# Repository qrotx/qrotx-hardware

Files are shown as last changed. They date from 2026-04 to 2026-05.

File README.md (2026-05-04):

# qrotx Singleband Transmitter Hardware

This is work in progress, it has not yet been tested. Description and calculations will be added later.

## Cloning

This repository uses a git submodule for the KiCad symbol and footprint libraries. Clone with:

```bash
git clone --recurse-submodules git@github.com:qrotx/qrotx-singleband-hw.git
```

If you already cloned without `--recurse-submodules`, initialize the submodule with:

```bash
git submodule update --init
```

## Assembly

### NUCLEO-G474RE Board Modifications

The NUCLEO-G474RE board requires the following modifications before mounting on the PCB.
Reference: [UM2505 STM32G4 Nucleo-64 boards (MB1367) user manual](https://www.st.com/resource/en/user_manual/um2505-stm32g4-nucleo64-boards-mb1367-stmicroelectronics.pdf)

#### Power Supply (JP5)

Change jumper JP5 from the default **5V_STLK** position to the **E5V** position. This powers the
Nucleo board from the E5V pin supplied by the PCB instead of from USB.

#### HSE Clock — Oscillator from External PF0 (Section 7.5.1)

Modify the following solder bridges to configure the HSE clock input for an external
oscillator on PF0:

| Solder Bridge | Default | Required |
|---|---|---|
| SB24 | OFF | OFF |
| SB25 | ON | OFF |
| SB26 | ON | OFF |
| SB27 | OFF | OFF |
| SB28 | OFF | ON |

## License
These hardware designs are made available under the CERN Open Hardware Licence Version 2 - Strongly Reciprocal.
See [LICENSE](LICENSE) for the full text.

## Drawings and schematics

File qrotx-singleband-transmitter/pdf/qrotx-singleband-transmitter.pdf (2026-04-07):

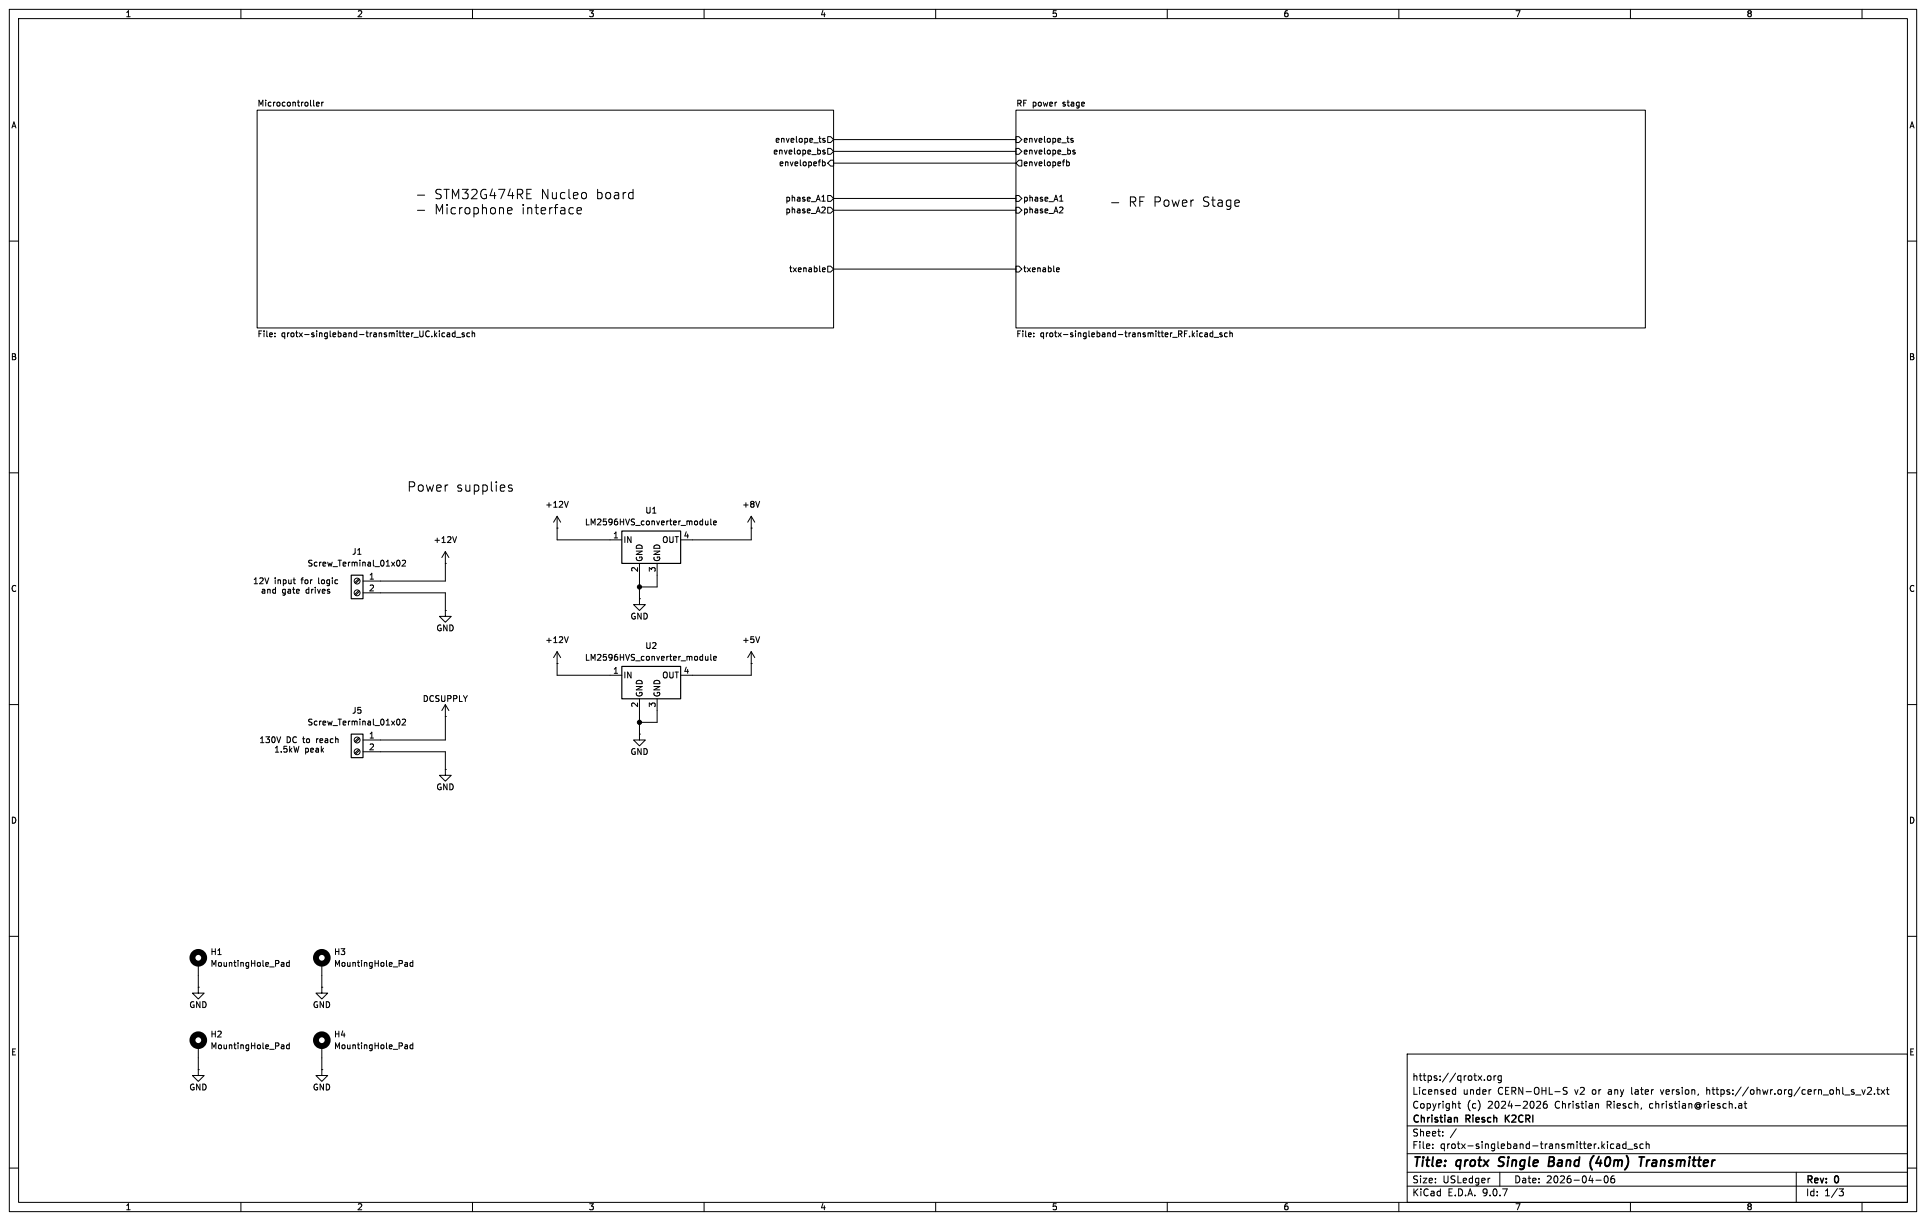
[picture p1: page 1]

txenable Microcontroller File: qrotx-singleband-transmitter_UC.kicad_sch

envelope_bs RF power stage File: qrotx-singleband-transmitter_RF.kicad_sch

12V input for logic and gate drives

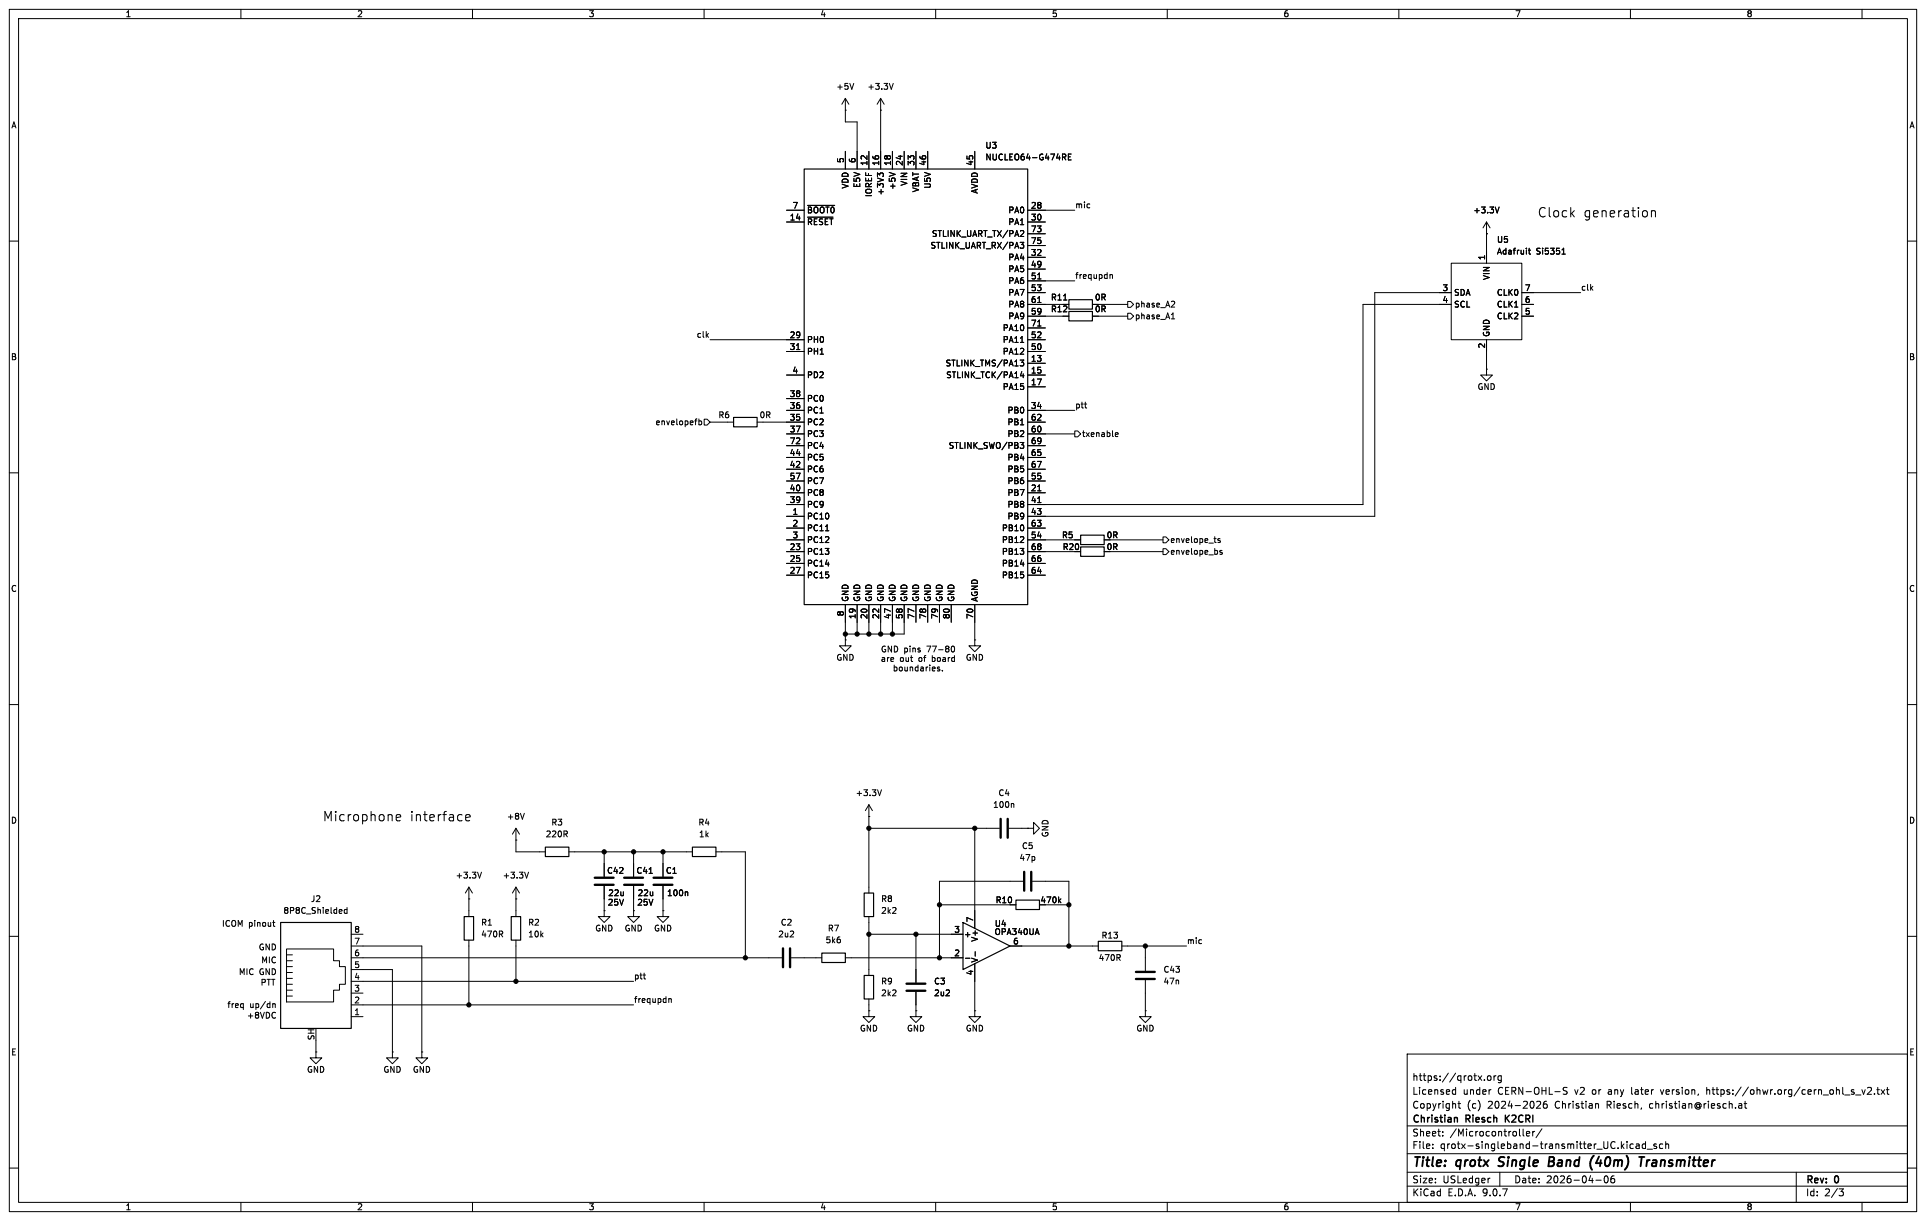
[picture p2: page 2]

6 GND 19 IOREF 12 GND 20 +3V3 16 GND 22 +5V 18 GND 47 VIN 24 GND 58 VBAT 33 GND 77 U5V 46 GND 78 GND 79 GND 80 AVDD 45 AGND 70 PA0 28 PA1 30 STLINK_UART_TX/PA2 73 STLINK_UART_RX/PA3 75 PA4 32 PA5 49 PA6 51 PA7 53 PA8 61 PA9 59 PA10 71 PA11 52 PA12 50 STLINK_TMS/PA13 13 STLINK_TCK/PA14 15 PA15 17 PB0 34 PB1 62 PB2 60 STLINK_SWO/PB3 69 PB4 65 PB5 67 PB6 55 PB7 21 PB8 41 PB9 43 PB10 63 PB12 54 PB13 68 PB14 66 PB15 64

6 GND 19 IOREF 12 GND 20 +3V3 16 GND 22 +5V 18 GND 47 VIN 24 GND 58 VBAT 33 GND 77 U5V 46 GND 78 GND 79 GND 80 AVDD 45 AGND 70 PA0 28 PA1 30 STLINK_UART_TX/PA2 73 STLINK_UART_RX/PA3 75 PA4 32 PA5 49 PA6 51 PA7 53 PA8 61 PA9 59 PA10 71 PA11 52 PA12 50 STLINK_TMS/PA13 13 STLINK_TCK/PA14 15 PA15 17 PB0 34 PB1 62 PB2 60 STLINK_SWO/PB3 69 PB4 65 PB5 67 PB6 55 PB7 21 PB8 41 PB9 43 PB10 63 PB12 54 PB13 68 PB14 66 PB15 64 R11 0R

are out of board

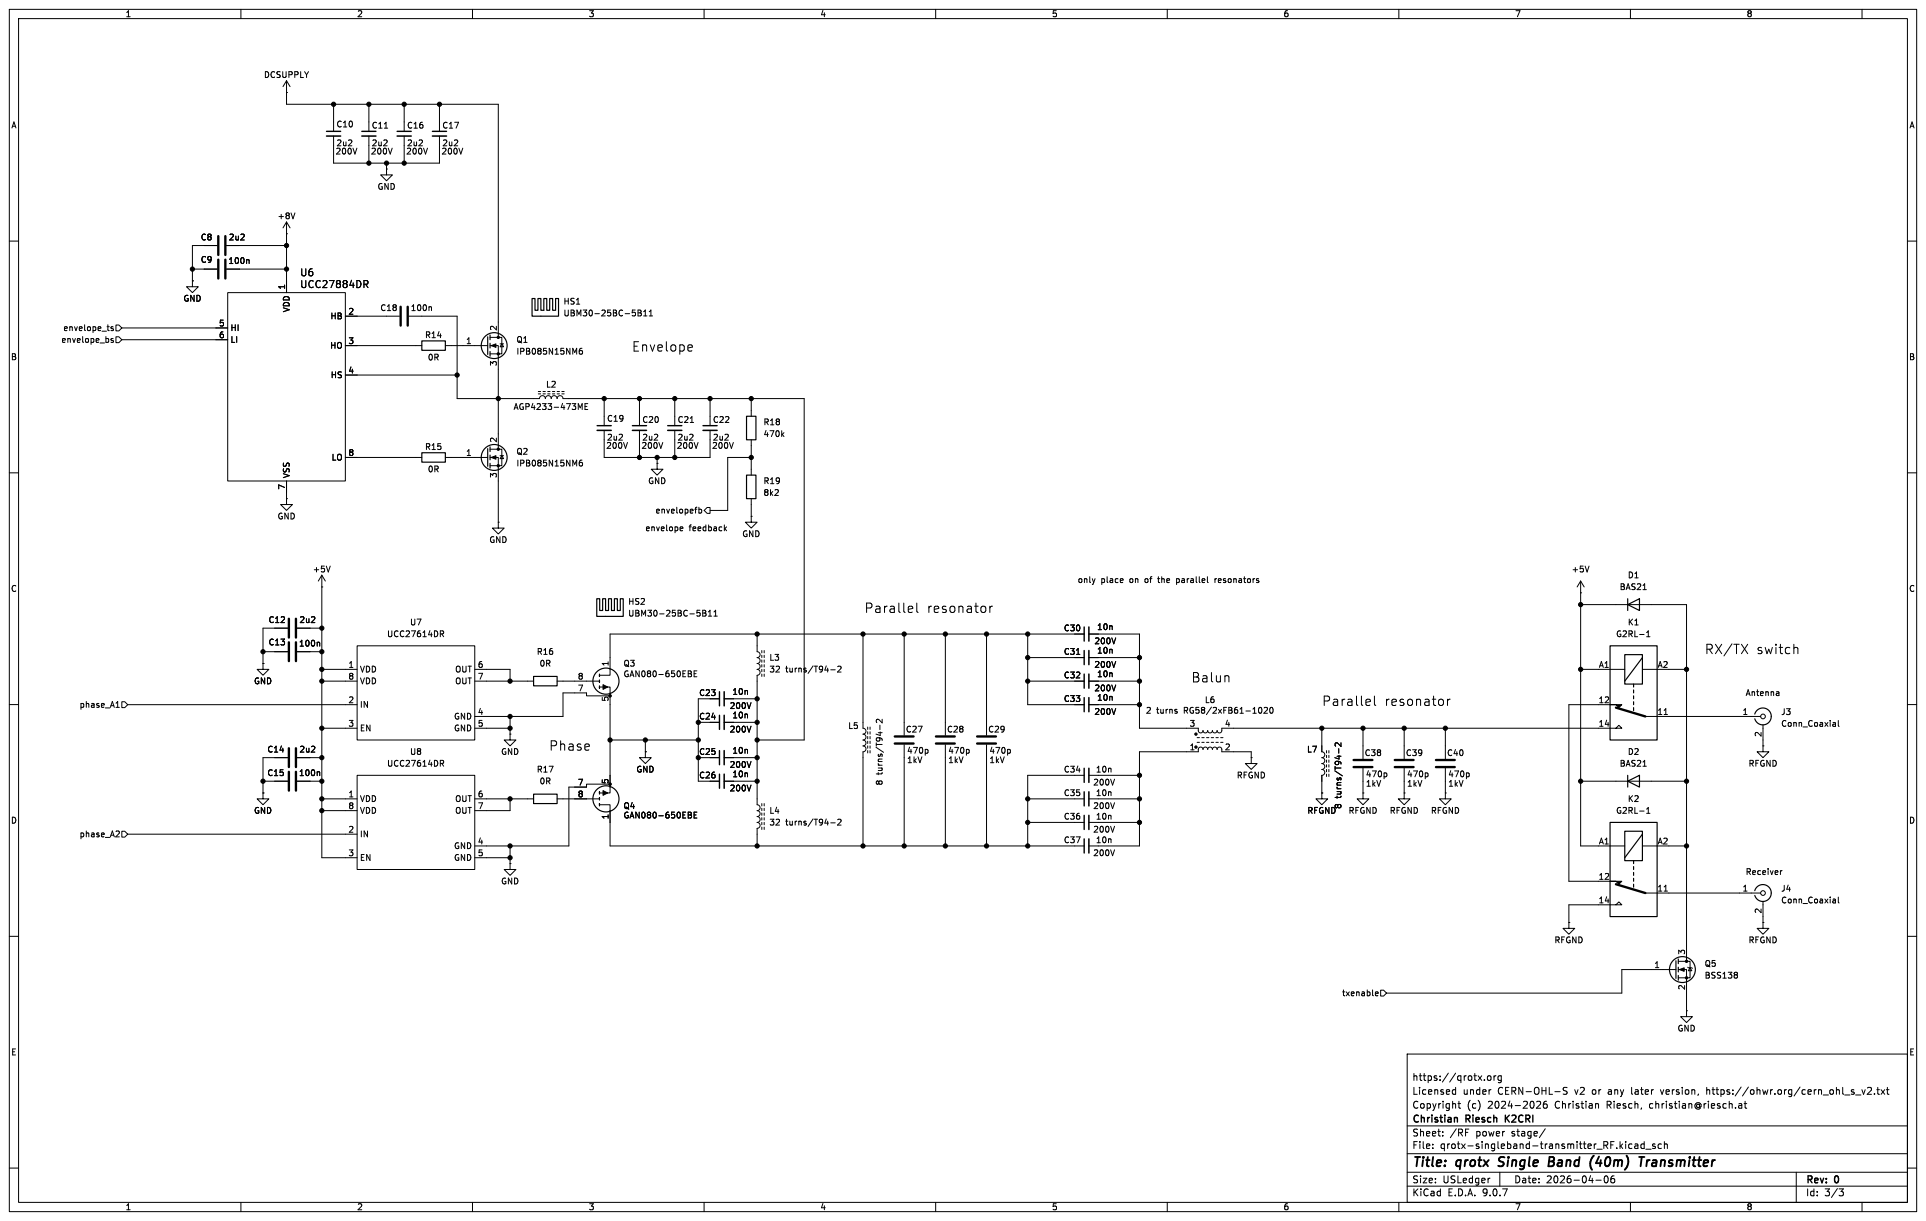
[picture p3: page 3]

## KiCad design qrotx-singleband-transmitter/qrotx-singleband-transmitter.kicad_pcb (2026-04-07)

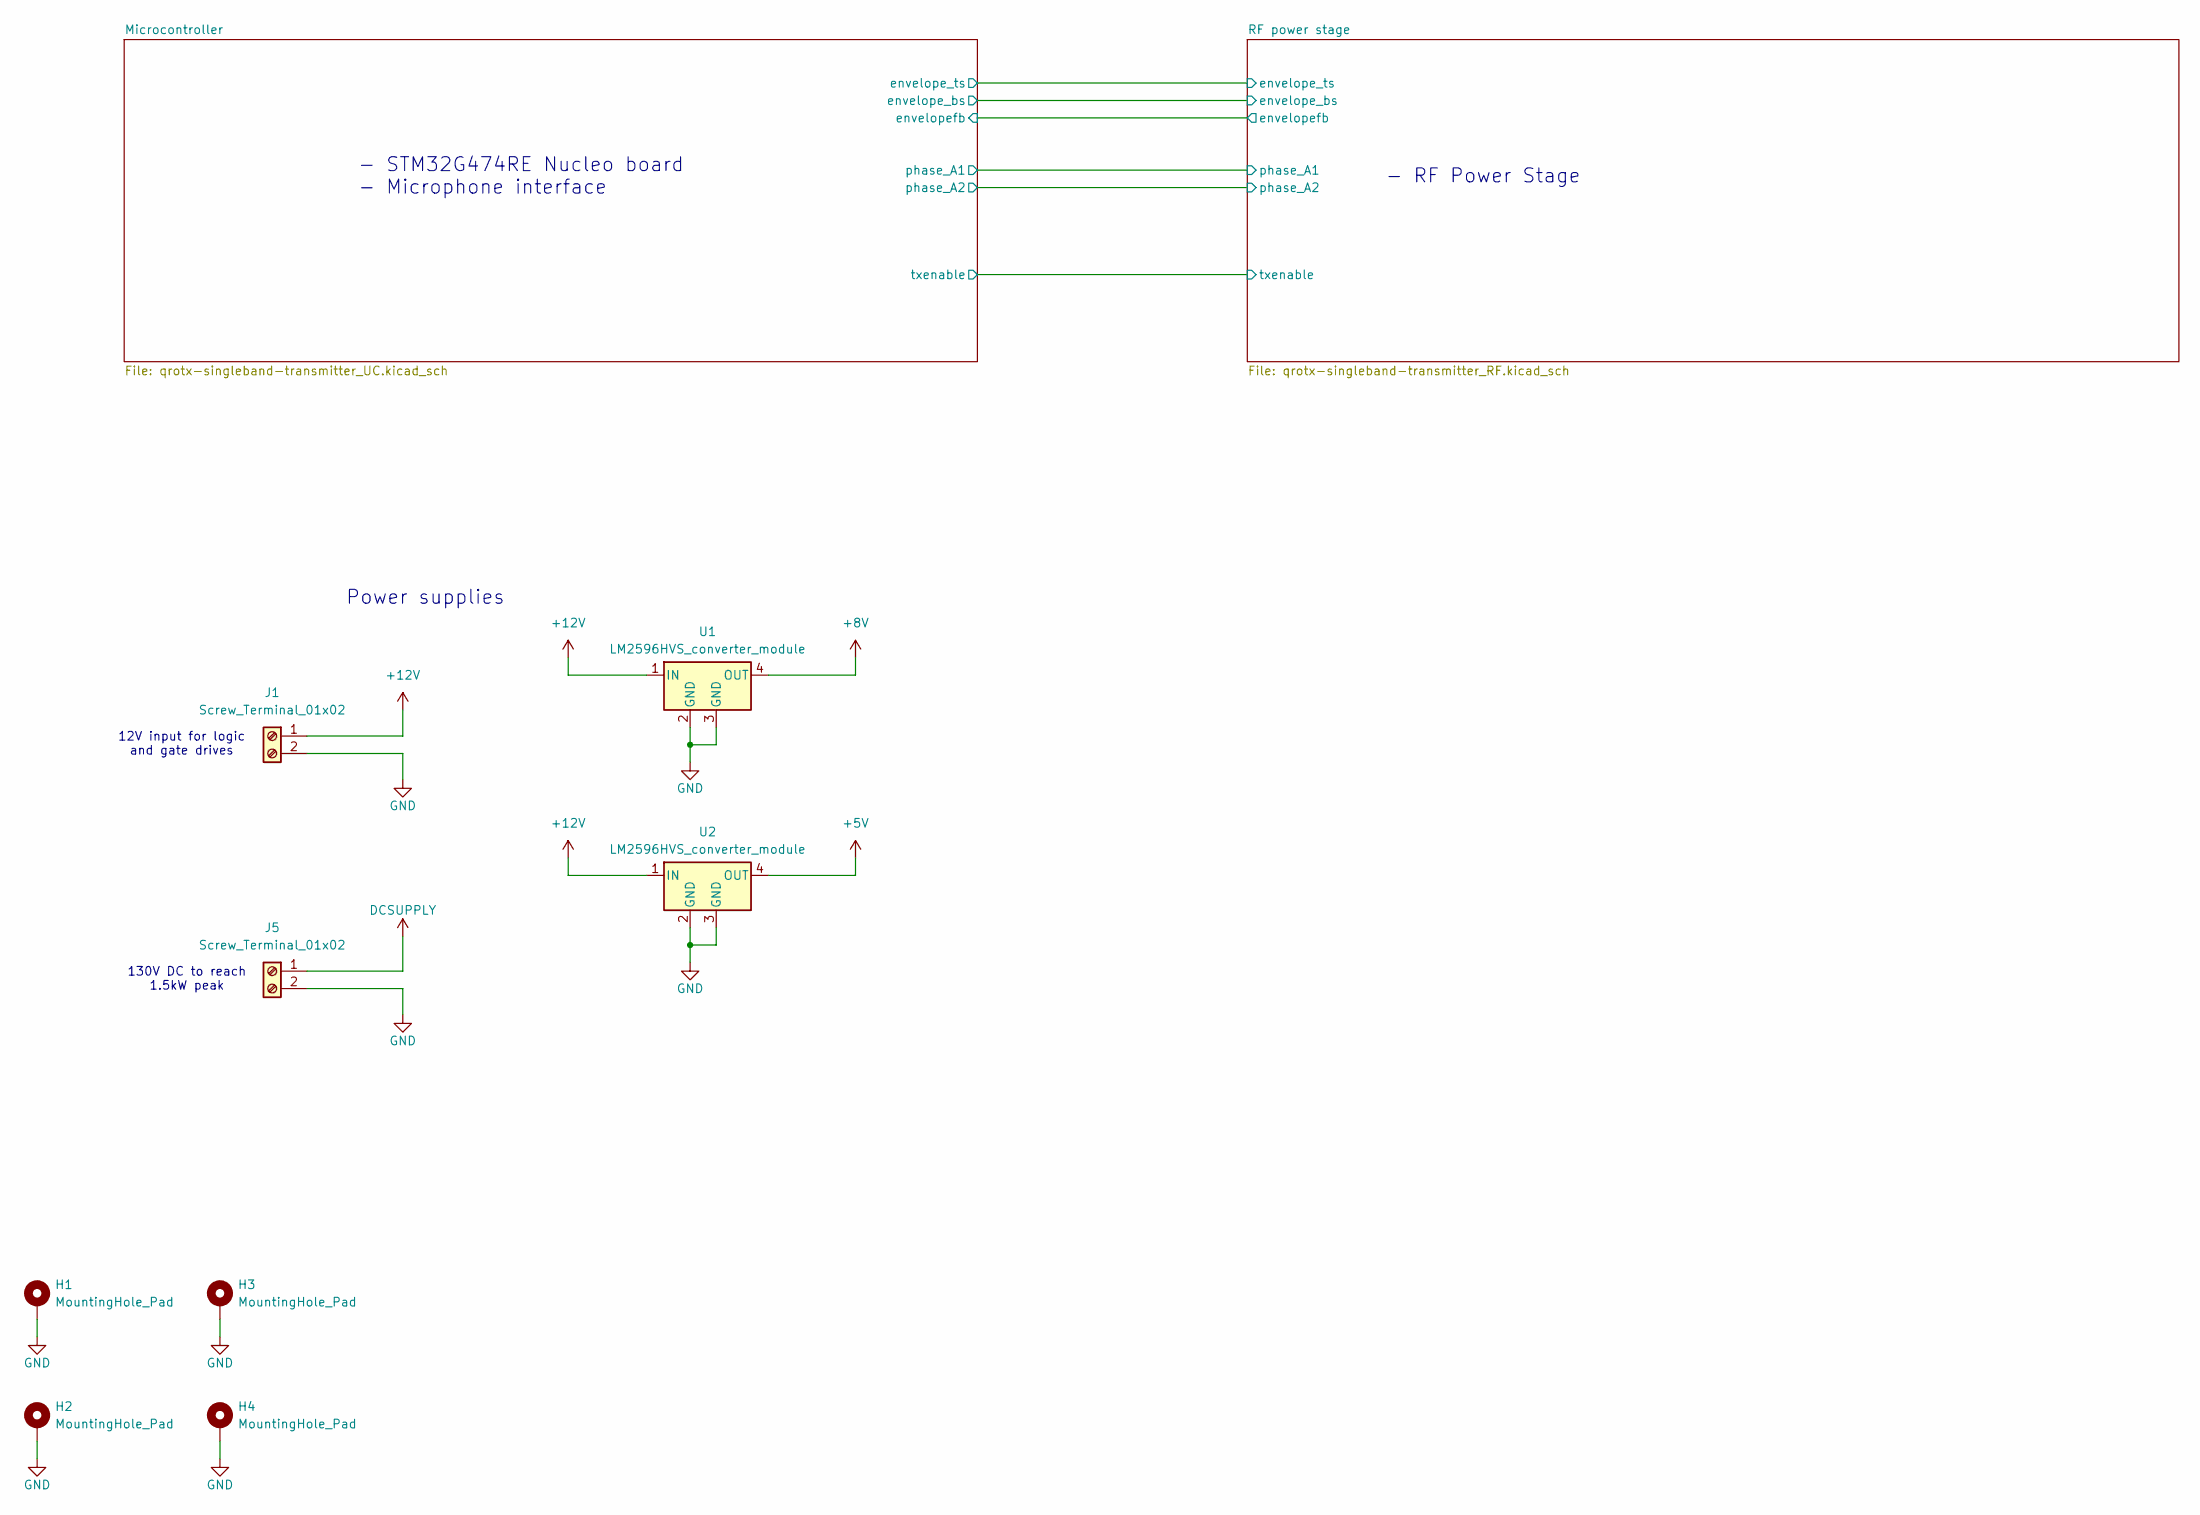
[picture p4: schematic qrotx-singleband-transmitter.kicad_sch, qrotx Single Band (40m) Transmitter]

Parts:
H1, H2, H3, H4: MountingHole_Pad; MountingHole_3.2mm_M3_Pad
J1, J5: Screw_Terminal_01x02; PhoenixContact_GMSTBV_2,5_2-GF-7,62_1x02_P7.62mm_Vertical_T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
U1, U2: LM2596HVS_converter_module; LM2596HVS module

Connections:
+5V: U2.4 (OUT); also elsewhere on the board
+8V: U1.4 (OUT); also elsewhere on the board
+12V: J1.1, U1.1 (IN), U2.1 (IN)
DCSUPPLY: J5.1; also elsewhere on the board
GND: H1.1, H2.1, H3.1, H4.1, J1.2, J5.2, U1.2 (GND), U1.3 (GND), U2.2 (GND), U2.3 (GND); also elsewhere on the board

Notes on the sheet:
Power supplies
130V DC to reach 1.5kW peak
- STM32G474RE Nucleo board - Microphone interface
12V input for logic and gate drives
- RF Power Stage

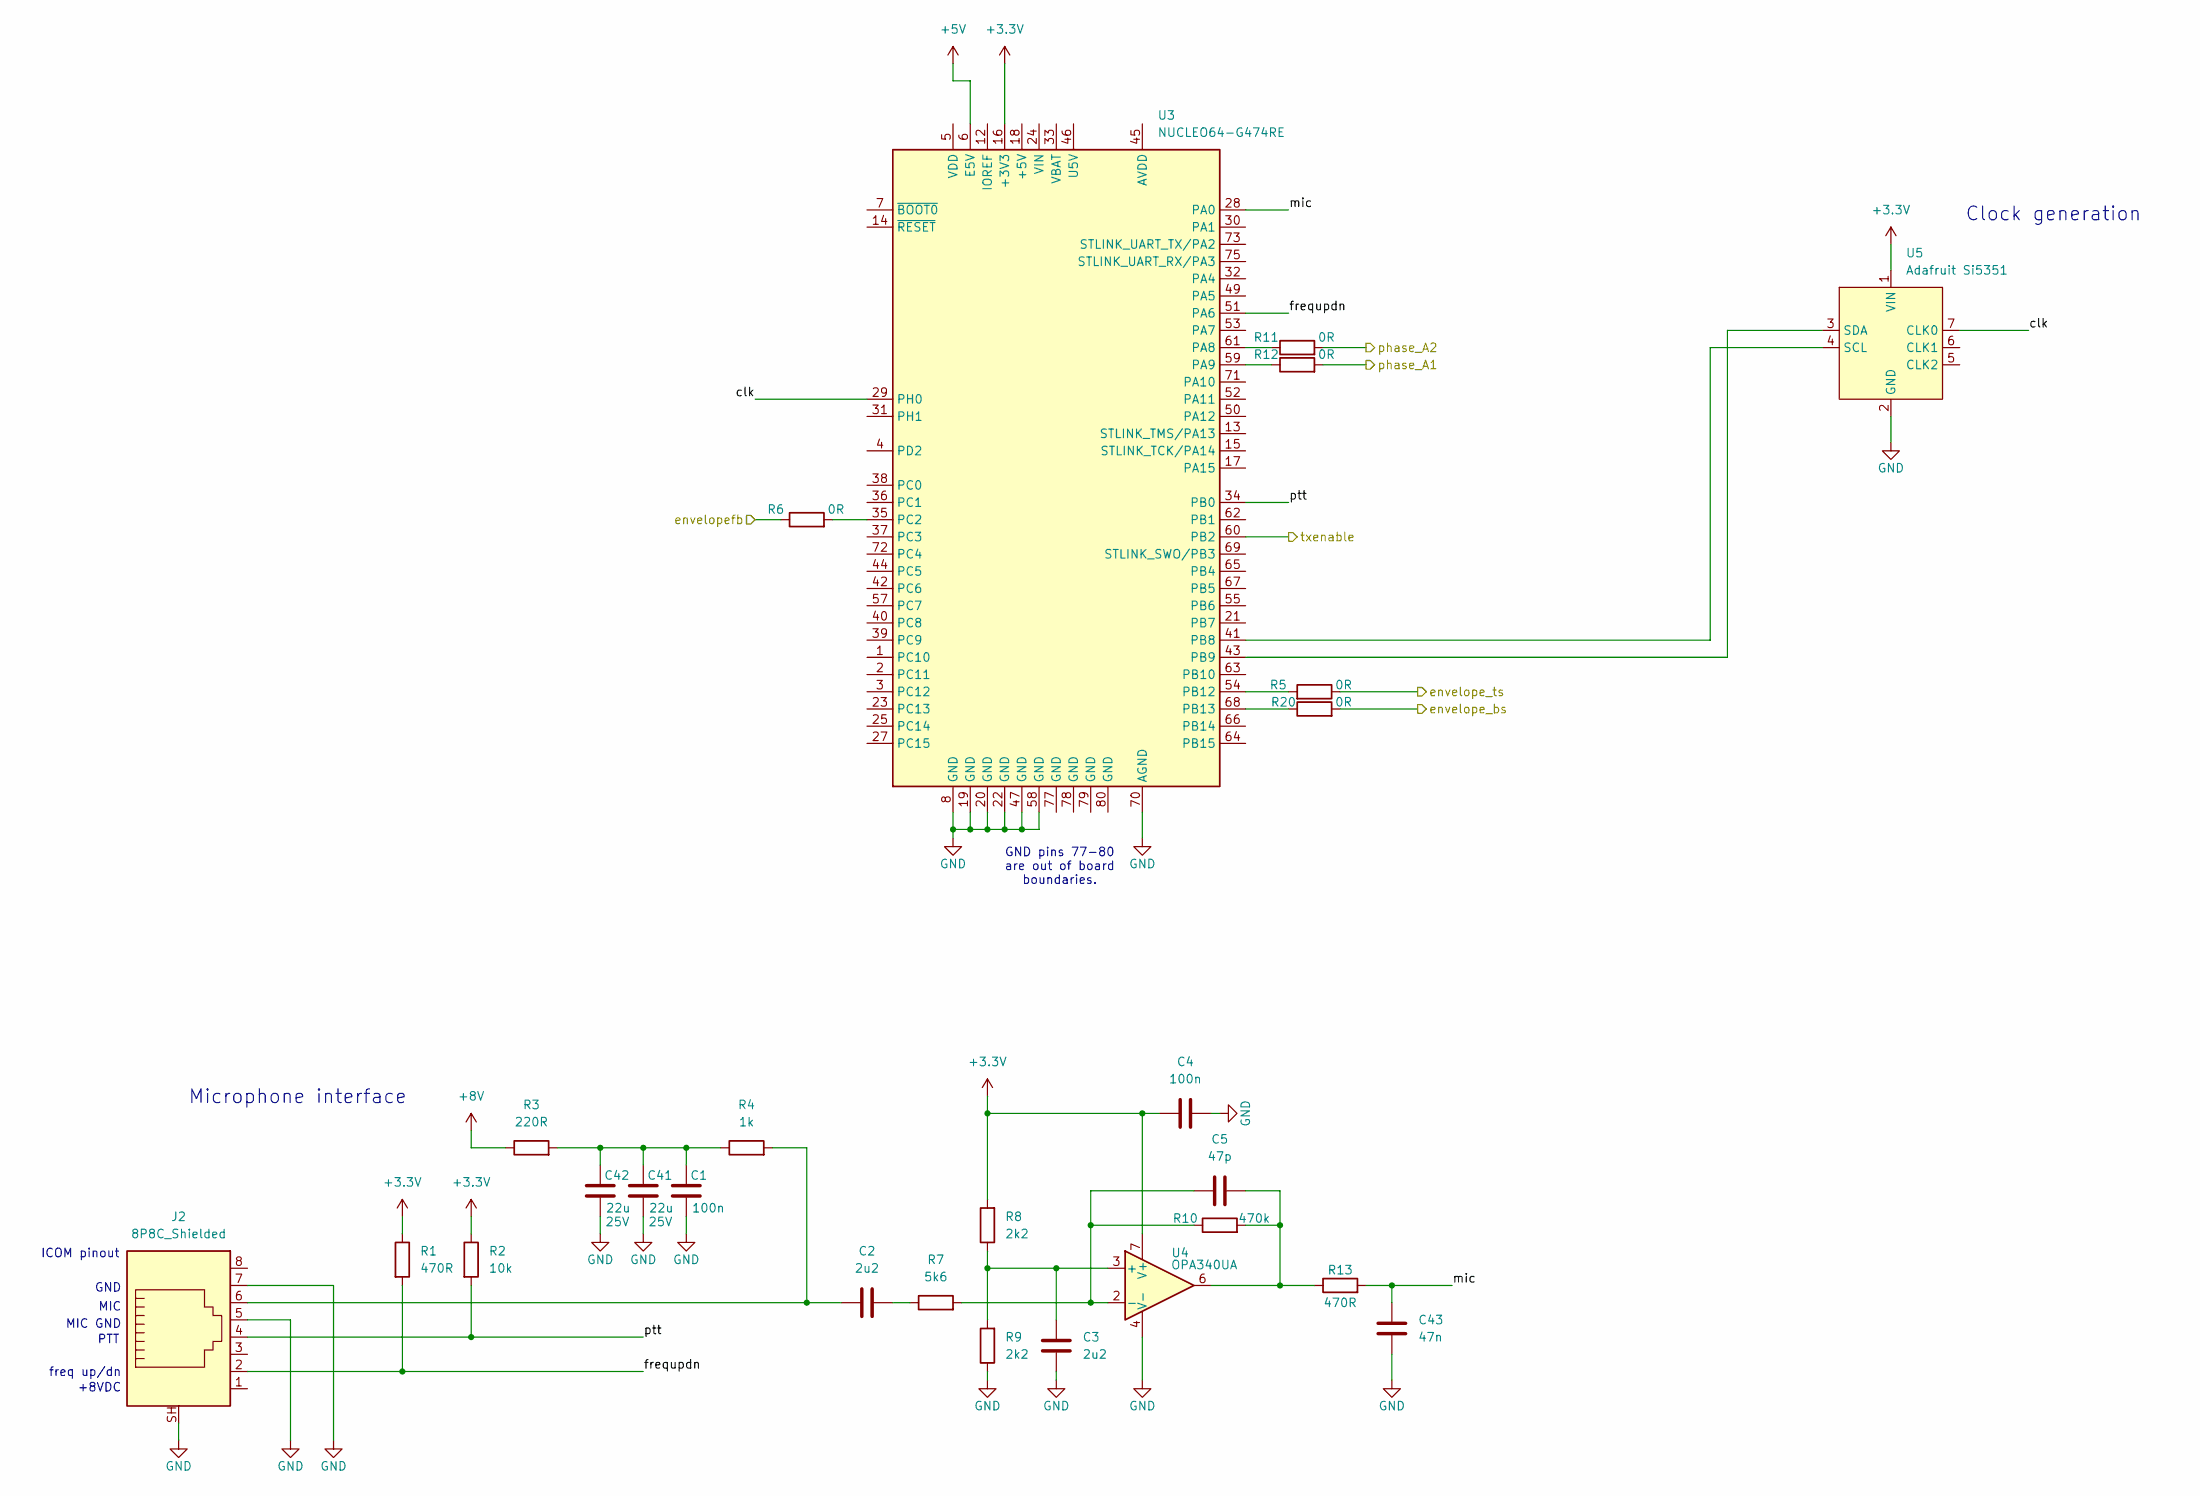
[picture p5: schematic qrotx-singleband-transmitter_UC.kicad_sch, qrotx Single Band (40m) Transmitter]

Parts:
C1, C4: 100n; C_0603_1608Metric
C2, C3: 2u2; C_0603_1608Metric
C5: 47p; C_0603_1608Metric
C41, C42: 22u; C_1210_3225Metric; Voltage 25V
C43: 47n; C_0603_1608Metric
J2: 8P8C_Shielded; RJ45_Amphenol_RJHSE5380
R1, R13: 470R; R_0603_1608Metric
R2: 10k; R_0603_1608Metric
R3: 220R; R_0603_1608Metric
R4: 1k; R_0603_1608Metric
R5, R6, R11, R12, R20: 0R; R_0603_1608Metric
R7: 5k6; R_0603_1608Metric
R8, R9: 2k2; R_0603_1608Metric
R10: 470k; R_0603_1608Metric
U3: NUCLEO64-G474RE; ST_Morpho_Connector_64_STLink
U4: OPA340UA; SOIC-8_3.9x4.9mm_P1.27mm
U5: Adafruit Si5351; Adafruit_Si5351

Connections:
+3.3V: C4.1, R1.1, R2.1, R8.2, U3.16 (+3V3), U4.7 (V+), U5.1 (VIN)
+5V: U3.6 (E5V); also elsewhere on the board
+8V: R3.1; also elsewhere on the board
/Microcontroller/clk: U3.29 (PH0), U5.7 (CLK0)
/Microcontroller/envelope_bs: R20.2; also elsewhere on the board
/Microcontroller/envelope_ts: R5.1; also elsewhere on the board
/Microcontroller/envelopefb: R6.1; also elsewhere on the board
/Microcontroller/frequpdn: J2.2, R1.2, U3.51 (PA6)
/Microcontroller/mic: C43.1, R13.2, U3.28 (PA0)
/Microcontroller/phase_A1: R12.2; also elsewhere on the board
/Microcontroller/phase_A2: R11.2; also elsewhere on the board
/Microcontroller/ptt: J2.4, R2.2, U3.34 (PB0)
/Microcontroller/txenable: U3.60 (PB2); also elsewhere on the board
GND: C1.2, C3.2, C4.2, C41.2, C42.2, C43.2, J2.5, J2.7, J2.SH, R9.1, U3.8 (GND), U3.19 (GND), U3.20 (GND), U3.22 (GND), U3.47 (GND), U3.58 (GND), U3.70 (AGND), U4.4 (V-), U5.2 (GND); also elsewhere on the board
unnamed: C1.1, C41.1, C42.1, R3.2, R4.1
unnamed: C2.1, J2.6, R4.2
unnamed: C2.2, R7.1
unnamed: C5.2, R10.2, R13.1, U4.6
unnamed: R11.1, U3.61 (PA8)
unnamed: R12.1, U3.59 (PA9)
unnamed: U3.41 (PB8), U5.4 (SCL)
unnamed: U3.43 (PB9), U5.3 (SDA)
unnamed: R5.2, U3.54 (PB12)
unnamed: R20.1, U3.68 (PB13)
unnamed: R6.2, U3.35 (PC2)
unnamed: C3.1, R8.1, R9.2, U4.3 (+)
unnamed: C5.1, R7.2, R10.1, U4.2 (-)

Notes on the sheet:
freq up/dn
ICOM pinout
GND
MIC
Clock generation
GND pins 77-80 are out of board boundaries.
+8VDC
PTT
Microphone interface
MIC GND

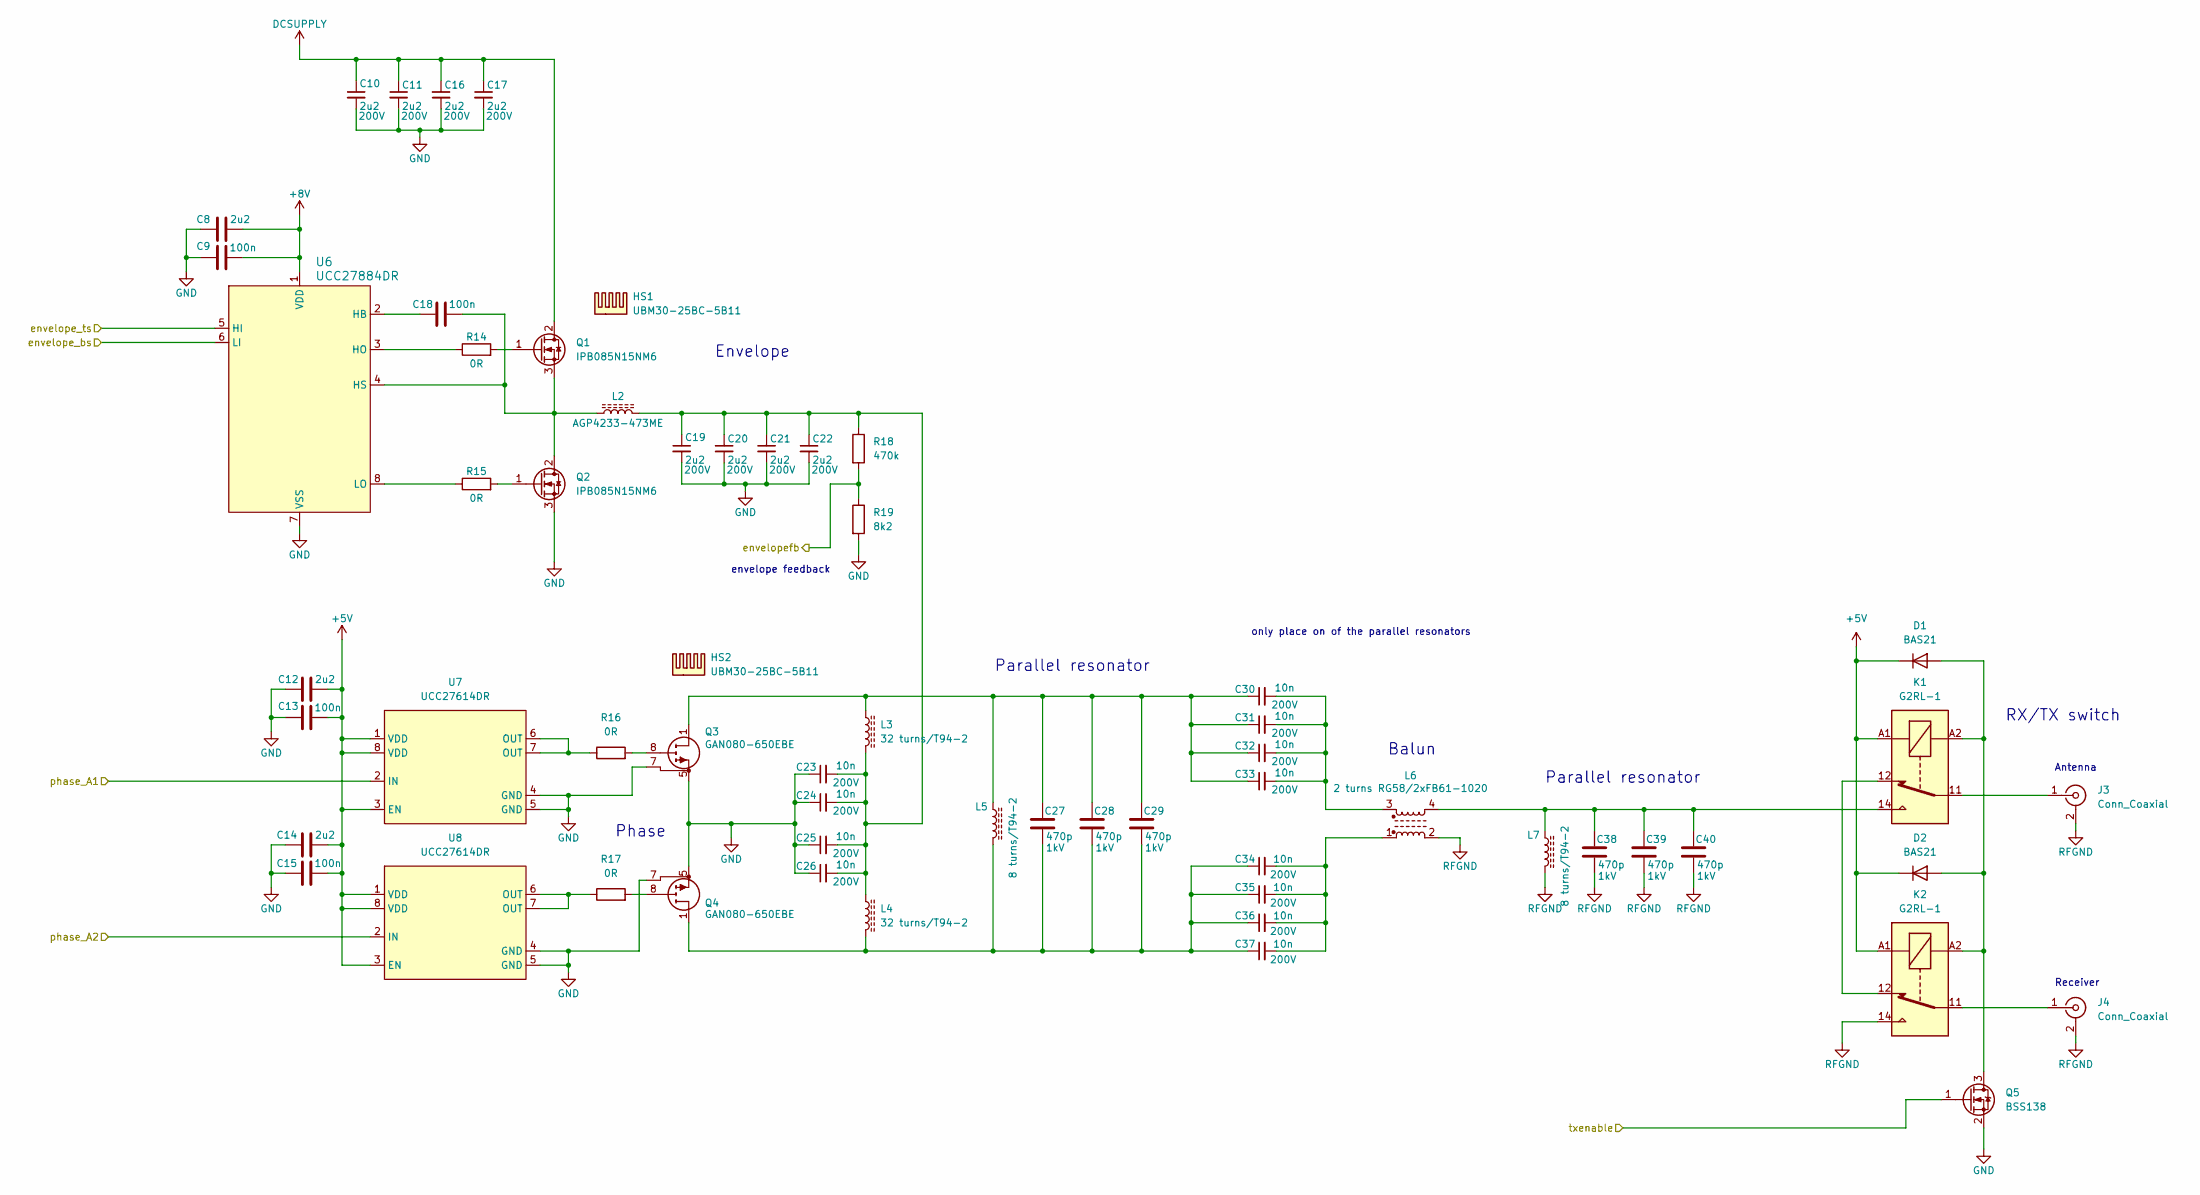
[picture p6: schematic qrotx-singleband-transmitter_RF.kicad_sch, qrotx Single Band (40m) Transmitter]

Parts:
C8, C12, C14: 2u2; C_0603_1608Metric
C9, C13, C15, C18: 100n; C_0603_1608Metric
C10, C11, C16, C17, C19, C20, C21, C22: 2u2; C_2220_5750Metric; Voltage 200V
C23, C24, C25, C26, C30, C31, C32, C33, C34, C35, C36, C37: 10n; C_1206_3216Metric; Voltage 200V
C27, C28, C29, C38, C39, C40: 470p; C_1206_3216Metric; Voltage 1kV
D1, D2: BAS21; SOT-23
HS1, HS2: UBM30-25BC-5B11; Heatsink_Alpha_UBM30-xxBP
J3: Conn_Coaxial; RF_output_pins
J4: Conn_Coaxial; SMA_Amphenol_901-144_Vertical
K1, K2: G2RL-1; Relay_SPDT_Omron_G2RL-1
L2: AGP4233-473ME; AGP4233-682-154
L3, L4: 32 turns/T94-2; t94-2_inductor_narrow
L5, L7: 8 turns/T94-2; t94-2_inductor
L6: 2 turns RG58/2xFB61-1020; tline_balun_pads
Q1, Q2: IPB085N15NM6; TO-263-2_ThermalVias
Q3, Q4: GAN080-650EBE; DFN8080-8_ThermalVias
Q5: BSS138; SOT-23
R14, R15, R16, R17: 0R; R_0603_1608Metric
R18: 470k; R_0603_1608Metric
R19: 8k2; R_0603_1608Metric
U6: UCC27884DR; SOIC-8_3.9x4.9mm_P1.27mm
U7, U8: UCC27614DR; SOIC-8_3.9x4.9mm_P1.27mm

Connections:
+5V: C12.2, C13.2, C14.2, C15.2, D1.3 (K), D2.3 (K), K1.A1, K2.A1, U7.1 (VDD), U7.3 (EN), U7.8 (VDD), U8.1 (VDD), U8.3 (EN), U8.8 (VDD); also elsewhere on the board
+8V: C8.2, C9.2, U6.1 (VDD); also elsewhere on the board
/Microcontroller/envelope_bs: U6.6 (LI); also elsewhere on the board
/Microcontroller/envelope_ts: U6.5 (HI); also elsewhere on the board
/Microcontroller/envelopefb: R18.2, R19.1; also elsewhere on the board
/Microcontroller/phase_A1: U7.2 (IN); also elsewhere on the board
/Microcontroller/phase_A2: U8.2 (IN); also elsewhere on the board
/Microcontroller/txenable: Q5.1 (G); also elsewhere on the board
DCSUPPLY: C10.1, C11.1, C16.1, C17.1, Q1.2 (D); also elsewhere on the board
GND: C8.1, C9.1, C10.2, C11.2, C12.1, C13.1, C14.1, C15.1, C16.2, C17.2, C19.2, C20.2, C21.2, C22.2, C23.1, C24.1, C25.1, C26.1, Q2.3 (S), Q3.5 (S), Q3.6 (S), Q3.7 (SS), Q3.9 (S), Q4.5 (S), Q4.6 (S), Q4.7 (SS), Q4.9 (S), Q5.2 (S), R19.2, U6.7 (VSS), U7.4 (GND), U7.5 (GND), U8.4 (GND), U8.5 (GND); also elsewhere on the board
unnamed: C19.1, C20.1, C21.1, C22.1, C23.2, C24.2, C25.2, C26.2, L2.2, L3.2, L4.1, R18.1
unnamed: C27.1, C28.1, C29.1, C30.1, C31.1, C32.1, C33.1, L3.1, L5.1, Q3.1 (D), Q3.2 (D), Q3.3 (D), Q3.4 (D)
unnamed: C27.2, C28.2, C29.2, C34.1, C35.1, C36.1, C37.1, L4.2, L5.2, Q4.1 (D), Q4.2 (D), Q4.3 (D), Q4.4 (D)
unnamed: C30.2, C31.2, C32.2, C33.2, L6.3
unnamed: C34.2, C35.2, C36.2, C37.2, L6.1
unnamed: C38.1, C39.1, C40.1, K1.14, L6.4, L7.1
unnamed: D1.1 (A), D2.1 (A), K1.A2, K2.A2, Q5.3 (D)
unnamed: J3.1 (In), K1.11
unnamed: J4.1 (In), K2.11
unnamed: K1.12, K2.12
unnamed: Q1.1 (G), R14.2
unnamed: C18.2, L2.1, Q1.3 (S), Q2.2 (D), U6.4 (HS)
unnamed: Q2.1 (G), R15.2
unnamed: Q3.8 (G), R16.2
unnamed: Q4.8 (G), R17.2
unnamed: R16.1, U7.6 (OUT), U7.7 (OUT)
unnamed: R17.1, U8.6 (OUT), U8.7 (OUT)
unnamed: C18.1, U6.2 (HB)
unnamed: R14.1, U6.3 (HO)
unnamed: R15.1, U6.8 (LO)
RFGND: C38.2, C39.2, C40.2, J3.2 (Ext), J4.2 (Ext), K2.14, L6.2, L7.2

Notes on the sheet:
Balun
Parallel resonator
Phase
only place on of the parallel resonators
envelope feedback
RX/TX switch
Envelope
Receiver
Antenna

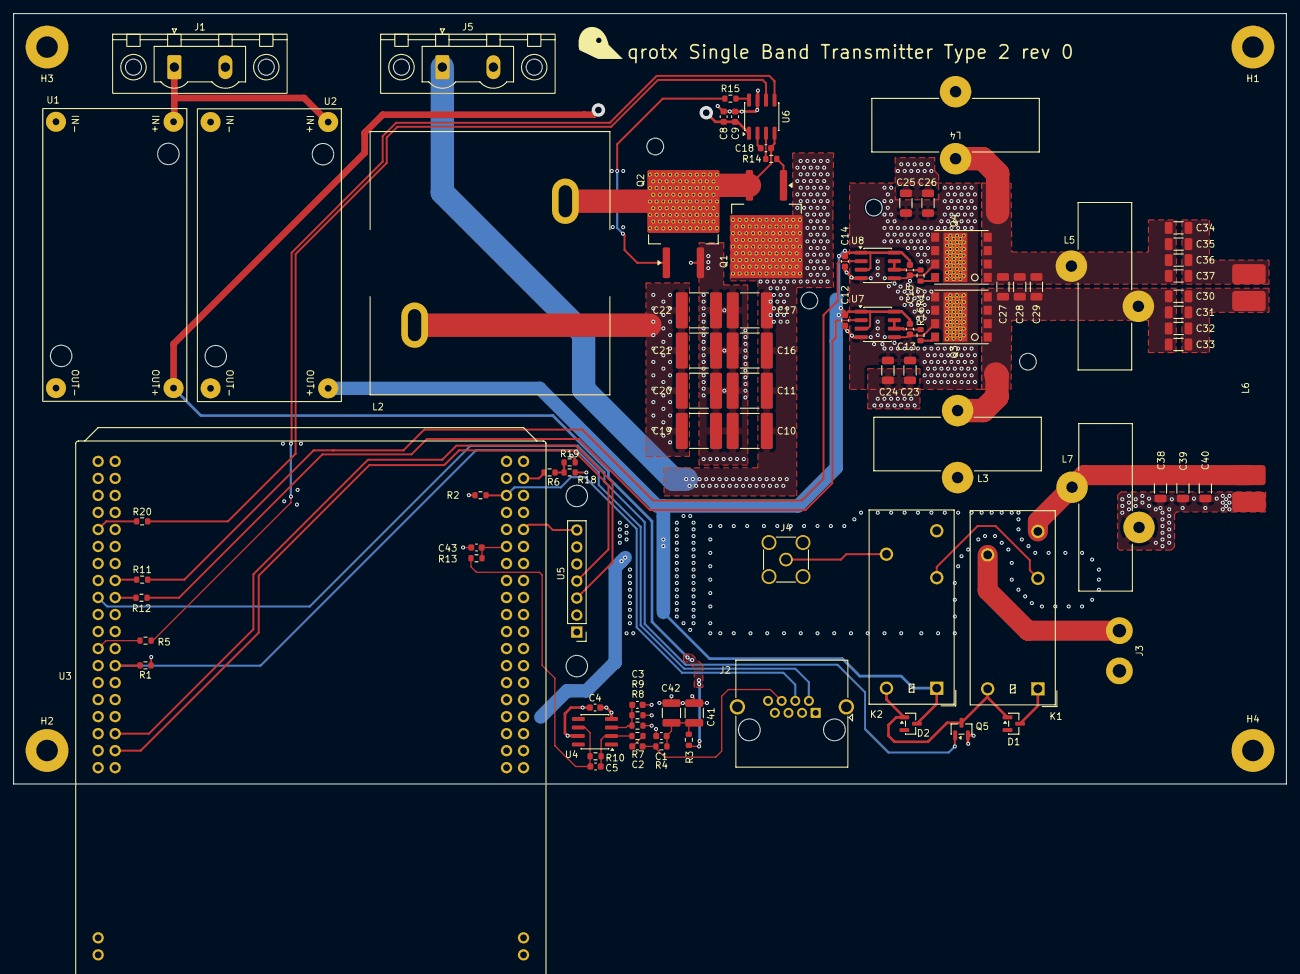
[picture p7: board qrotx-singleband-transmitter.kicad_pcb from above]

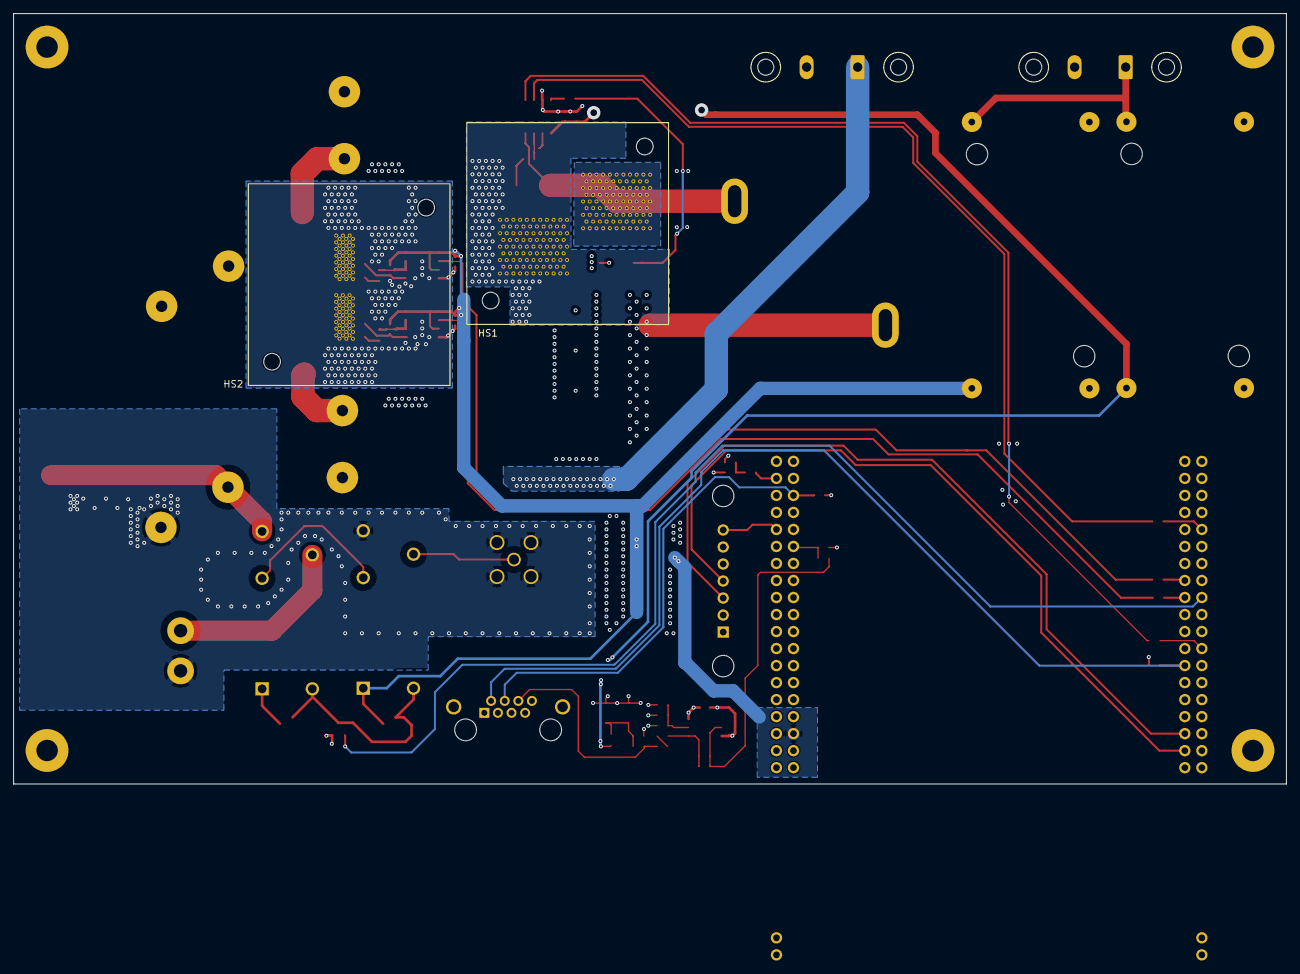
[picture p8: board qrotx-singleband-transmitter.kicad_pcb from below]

Board: 4 copper layers, 190.0 x 115.0 mm, 95 parts (2 on the bottom side), 50 nets.

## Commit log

2026-04-07 Initial design of the single band transmitter
    [qrotx-singleband-transmitter.kicad_pcb, qrotx-singleband-transmitter.kicad_sch, qrotx-singleband-transmitter_RF.kicad_sch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]
2026-04-07 Update text blocks in drawings
    [qrotx-singleband-transmitter.kicad_pcb, qrotx-singleband-transmitter.kicad_sch, qrotx-singleband-transmitter_RF.kicad_sch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]
2026-04-07 Add Kicad jobset to generate output and commit pdf
2026-05-04 Extract components into qrotx-components submodule
    KiCad symbols and footprints are now maintained in a separate repo
    (git@github.com:qrotx/qrotx-components.git) and included here as a submodule.
2026-05-04 Merge assembly instructions into README
    Move NUCLEO-G474RE modification steps from qrotx-singleband-transmitter/ASSEMBLY.md
    into a new Assembly section in the top-level README and remove the file.

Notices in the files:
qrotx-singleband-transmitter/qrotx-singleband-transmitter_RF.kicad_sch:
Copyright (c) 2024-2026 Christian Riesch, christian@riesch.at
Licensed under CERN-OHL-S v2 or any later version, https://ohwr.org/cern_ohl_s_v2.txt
